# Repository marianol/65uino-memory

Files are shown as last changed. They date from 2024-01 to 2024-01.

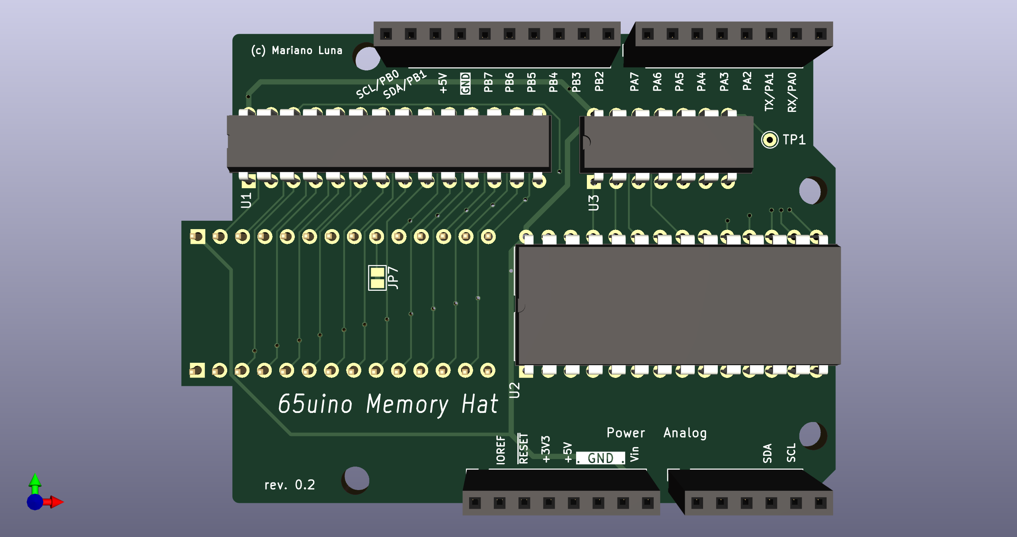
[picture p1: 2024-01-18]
pdf/65uino-memory-hat.png

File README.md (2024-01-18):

# 65uino Memory Hat

This is a hack Hat for the 65uino project to extend the memory to the maximum 4Kb minus the 256 bytes of Zero Page used by the RIOT memory and registers.

Is a hack Hat because it relocates the board ROM to the hat and uses pin headers to bring the ROM pins to the hat board. You will need to add some bodge wires to extend extra pins (A12 and R/WB) not available in the ROM socket.

This board has not been tested as of Rev. 0.2

## Memory Map
RIOT $0000-$00FF
RAM  $0100-$0FFF
ROM  $1000-$1FFF

## 65uino Project
The project author is Anders Nielsen and you can findit here https://github.com/AndersBNielsen/65uino/
You'll find more details at https://hackaday.io/project/190260-65uino

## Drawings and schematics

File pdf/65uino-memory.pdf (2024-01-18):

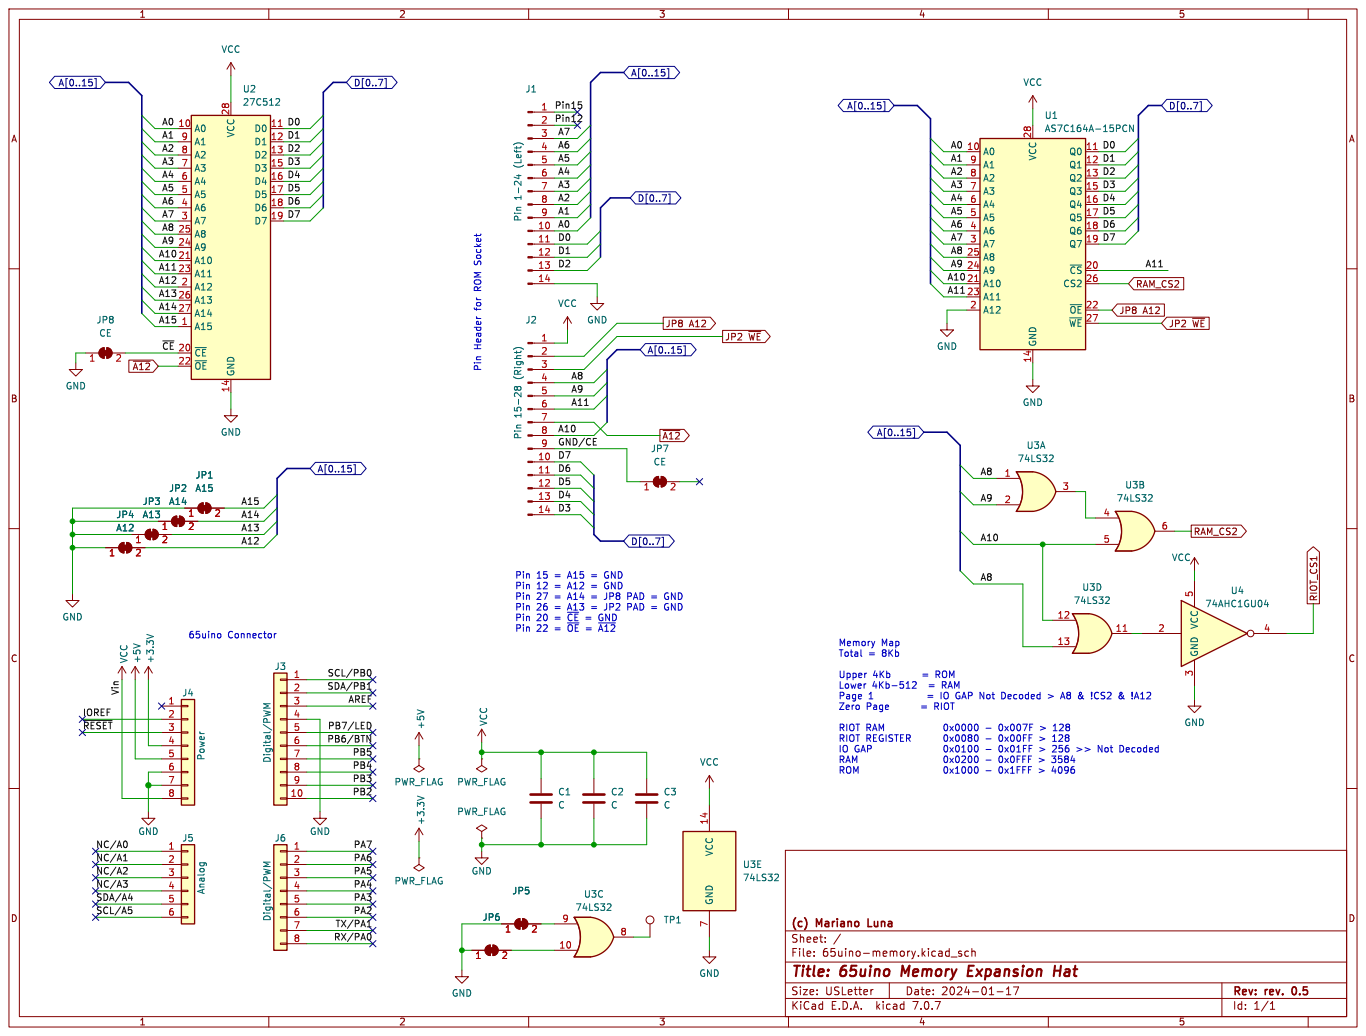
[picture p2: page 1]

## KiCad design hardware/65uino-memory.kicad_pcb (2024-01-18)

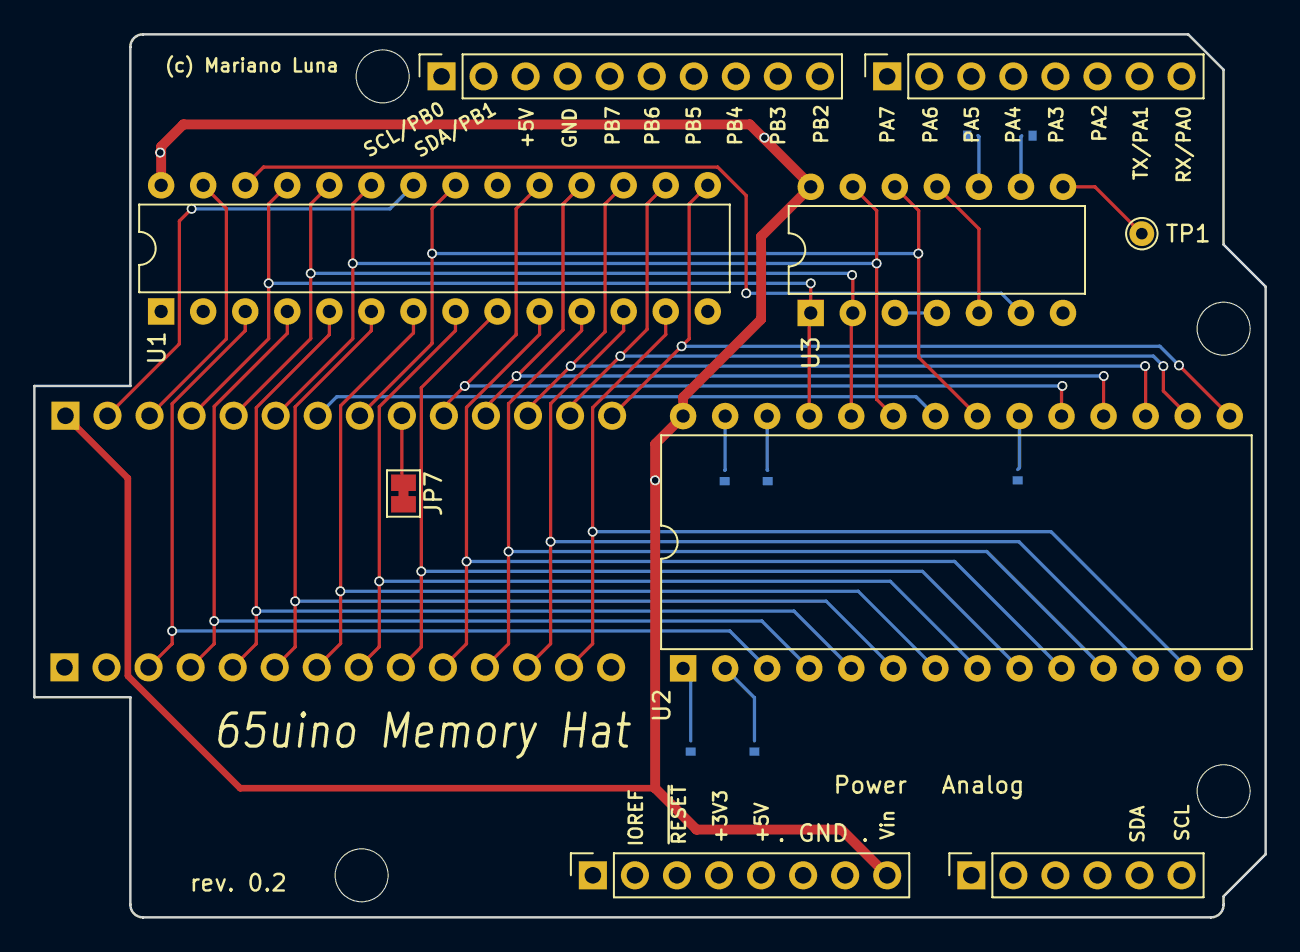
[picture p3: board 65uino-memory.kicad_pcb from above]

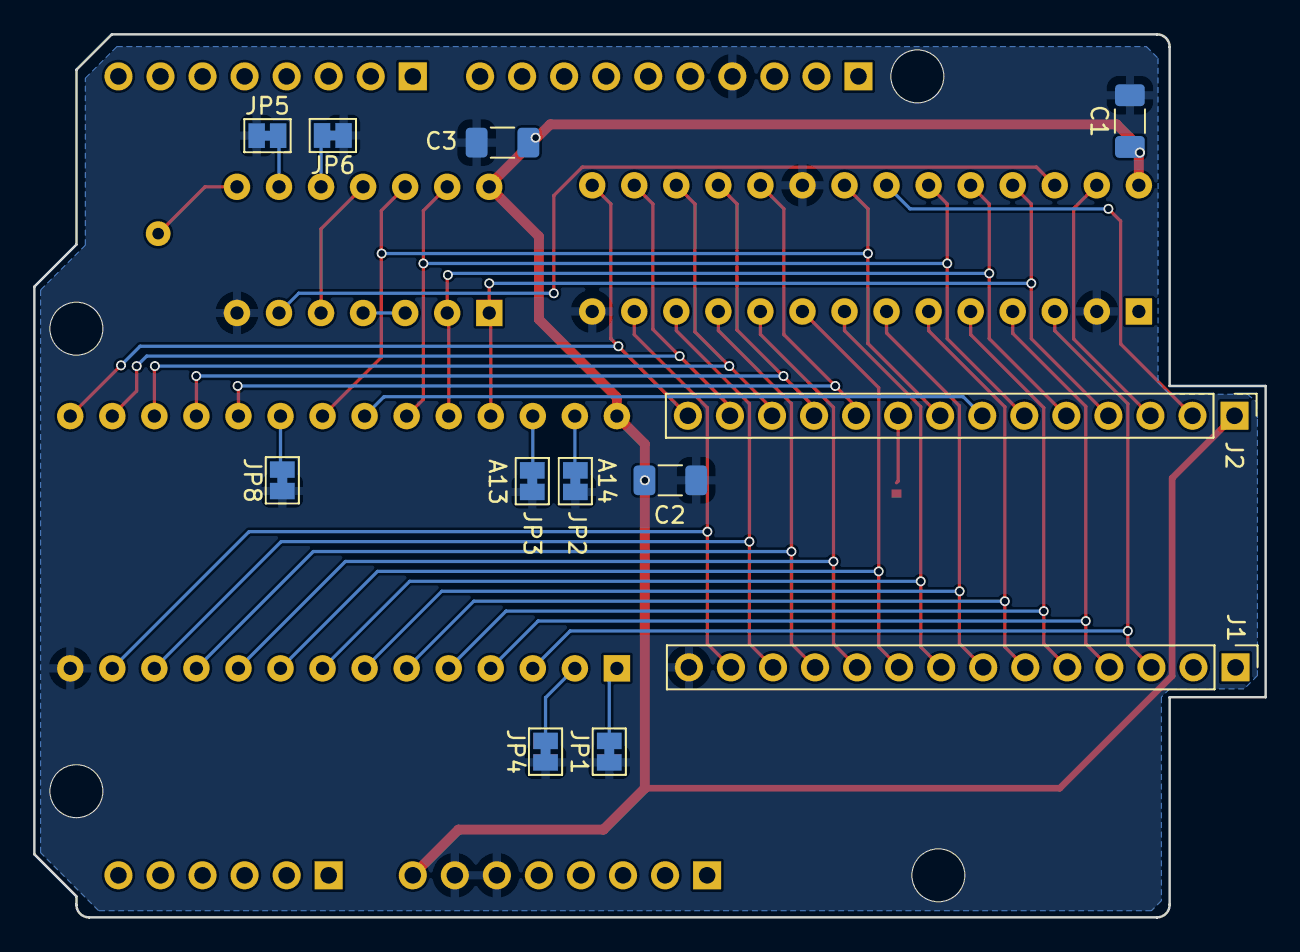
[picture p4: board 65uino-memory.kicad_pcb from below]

Board: 2 copper layers, 74.4 x 53.3 mm, 25 parts (12 on the bottom side), 37 nets.

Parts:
C1, C2, C3: C; C_1206_3216Metric_Pad1.33x1.80mm_HandSolder
J1, J2: Conn_01x14_Pin; PinHeader_1x14_P2.54mm_Vertical
J3: Digital/PWM; PinSocket_1x10_P2.54mm_Vertical
J4: Power; PinSocket_1x08_P2.54mm_Vertical
J5: Analog; PinSocket_1x06_P2.54mm_Vertical
J6: Digital/PWM; PinSocket_1x08_P2.54mm_Vertical
JP1: A15; SolderJumper-2_P1.3mm_Bridged_Pad1.0x1.5mm
JP2: A14; SolderJumper-2_P1.3mm_Bridged_Pad1.0x1.5mm
JP3: A13; SolderJumper-2_P1.3mm_Bridged_Pad1.0x1.5mm
JP4: A12; SolderJumper-2_P1.3mm_Bridged_Pad1.0x1.5mm
JP5, JP6: SolderJumper-2_P1.3mm_Bridged_Pad1.0x1.5mm
JP7, JP8: CE; SolderJumper-2_P1.3mm_Bridged_Pad1.0x1.5mm
MH1, MH2, MH3, MH4: MountingHole_3.2mm
TP1: TestPoint_THTPad_D1.5mm_Drill0.7mm
U1: AS7C164A-15PCN; DIP-28_W7.62mm
U2: 27C512; DIP-28_W15.24mm
U3: 74LS32; DIP-14_W7.62mm

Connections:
/GND/CE: J2.9, JP7.1 (A)
/~CE: JP8.2 (B), U2.20 (~CE)
A0: J1.10, U1.10 (A0), U2.10 (A0)
A1: J1.9, U1.9 (A1), U2.9 (A1)
A2: J1.8, U1.8 (A2), U2.8 (A2)
A3: J1.7, U1.7 (A3), U2.7 (A3)
A4: J1.6, U1.6 (A4), U2.6 (A4)
A5: J1.5, U1.5 (A5), U2.5 (A5)
A6: J1.4, U1.4 (A6), U2.4 (A6)
A7: J1.3, U1.3 (A7), U2.3 (A7)
A8: J2.4, U1.25 (A8), U2.25 (A8), U3.1
A9: J2.5, U1.24 (A9), U2.24 (A9), U3.2
A10: J2.8, U1.21 (A10), U2.21 (A10), U3.12
A11: J2.6, U1.23 (A11), U2.23 (A11), U3.13
A12: JP4.2 (B), U2.2 (A12)
A13: JP3.2 (B), U2.26 (A13)
A14: JP2.2 (B), U2.27 (A14)
A15: JP1.2 (B), U2.1 (A15)
D0: J1.11, U1.11 (Q0), U2.11 (D0)
D1: J1.12, U1.12 (Q1), U2.12 (D1)
D2: J1.13, U1.13 (Q2), U2.13 (D2)
D3: J2.14, U1.15 (Q3), U2.15 (D3)
D4: J2.13, U1.16 (Q4), U2.16 (D4)
D5: J2.12, U1.17 (Q5), U2.17 (D5)
D6: J2.11, U1.18 (Q6), U2.18 (D6)
D7: J2.10, U1.19 (Q7), U2.19 (D7)
GND: C1.2, C2.2, C3.2, J1.14, J3.4, J4.6, J4.7, JP1.1 (A), JP2.1 (A), JP3.1 (A), JP4.1 (A), JP5.1 (A), JP6.1 (A), JP8.1 (A), U1.2 (A12), U1.14 (GND), U1.20 (~CS), U2.14 (GND), U3.7 (GND)
JP2 ~WE: J2.3, U1.27 (~WE)
JP8 A12: J2.2, U1.22 (~OE)
unnamed: JP5.2 (B), U3.9
unnamed: JP6.2 (B), U3.10
unnamed: TP1.1, U3.8
unnamed: U3.3, U3.4
unnamed: U3.5, U3.11
RAM_CS2: U1.26 (CS2), U3.6
VCC: C1.1, C2.1, C3.1, J2.1, J4.8, U1.28 (VCC), U2.28 (VCC), U3.14 (VCC)
~A12: J2.7, U2.22 (~OE)
